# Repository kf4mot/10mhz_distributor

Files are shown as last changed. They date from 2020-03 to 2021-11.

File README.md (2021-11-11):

# 10mhz_distributor
A 10 MHz 3 channel distribution amplifier and low pass filter designed to integrate into a BG7TBL GPSDO. A 5th. order LPF on both the input and outputs allows it to be driven with either sine or square waves and produce a sine output of around 12 dBm into a 50Ω load.
Power consumption is about 130 mA @12V.

[Schematic](https://github.com/kf4mot/10mhz_distributor/blob/master/hardware/10mhz_distributor_r1.pdf)

[Created with KiCAD ver. 5.1.5-3](https://kicad.org)

**Notes worth reading**

1. Schematic and BOM show The Qorvo TQP369182 as the MMIC. TQP369180 was actually used on the first board. The extra gain of the 182 seems unnecessary when driven with a 5V square wave and it may cause oscillation based on past experience. Bias resistors remain at 91Ω. Upgrade at your own risk and let me know how it goes if you try it or any other MMIC.
1. Pads for a optional attn. are on the input. *Trace that shorts R2 should be cut.* **Untested.**
1. Pads for a optional isolation transformer are on the 3rd. output. **Untested.**
1. Jitter and delay/phase shift are untested, but assumed good enough for a inexpensive GPSDO. If you build it and have the lab to test please share your results.
1. I left the input BNC (J3) off of mine and ran a internal wire to the GPSDO output. The BNC could be added by those that want the option to loop the clock or any other suitable input back into the distribution amp. Or those that want to use this as a stand alone general purpose distribution amp.
1. The 50Ω input load (R11) is 0603 size because I happen to have it in my inventory. You could use a 1206 at the R1 position if prefered. Or probably left off altogether if you're driving with a sinewave and bypassing the input filter.
   
Attenuator table for 1% resistors
Attn. |R2 | R1, R3
------------ | ------------- | ---------
3 dB| 17.8Ω | 294Ω
6 dB| 37.4Ω | 150Ω
10 dB | 71.5Ω | 95.3Ω

[Attenuator Calc](https://www.pasternack.com/t-calculator-pi-attn.aspx)

[Licensed under CERN-OHL-S V2. Julian White, 2020](https://www.ohwr.org/project/cernohl/wikis/home)

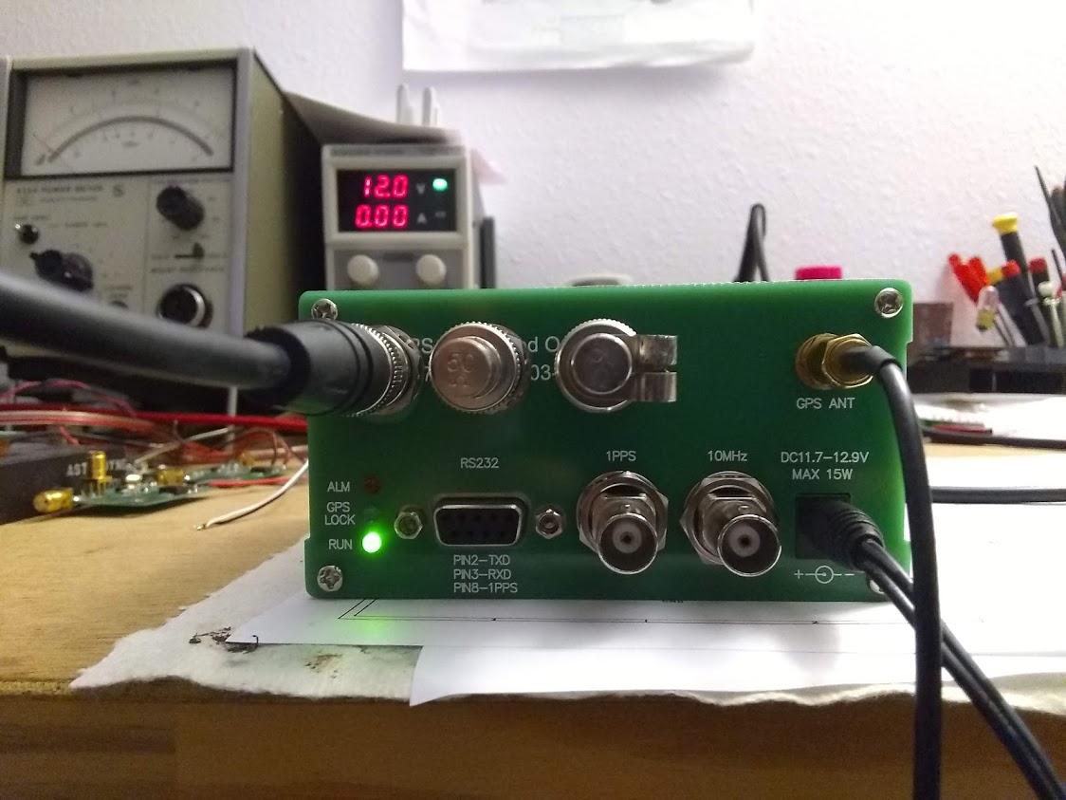
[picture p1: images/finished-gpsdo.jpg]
Complete


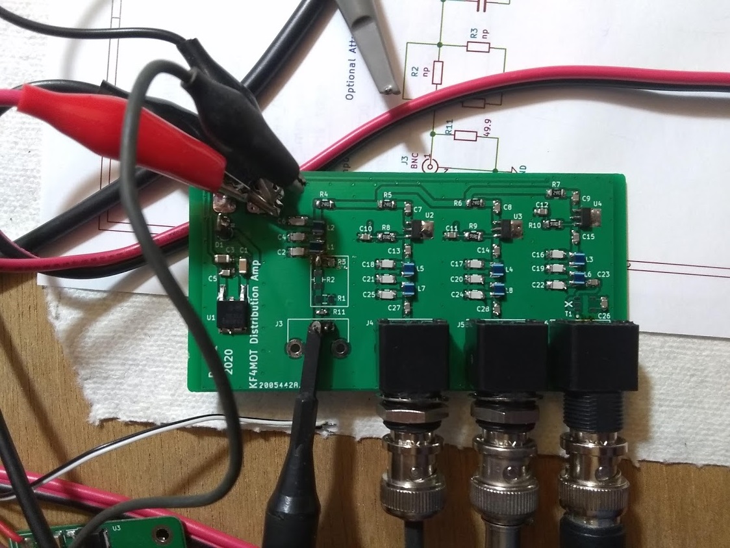
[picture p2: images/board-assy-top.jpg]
BoardTop Board Top


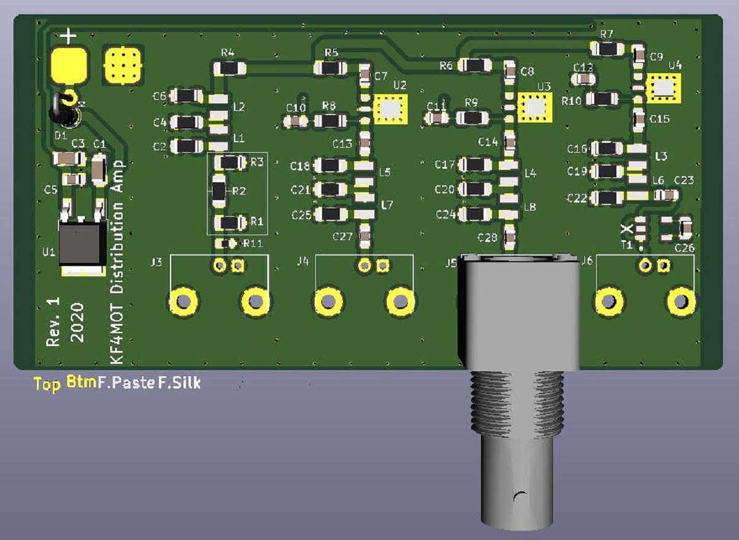
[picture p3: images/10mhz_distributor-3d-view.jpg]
BoardTop 3D Board Top 3D


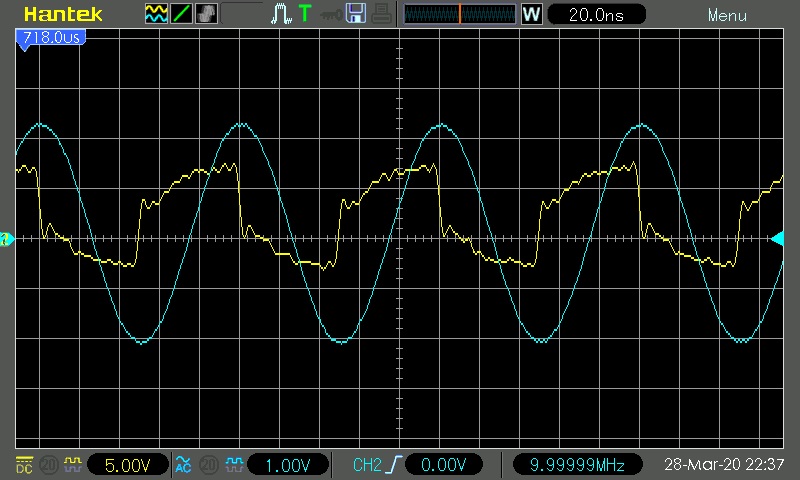
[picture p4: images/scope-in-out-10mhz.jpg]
Input vs. Output


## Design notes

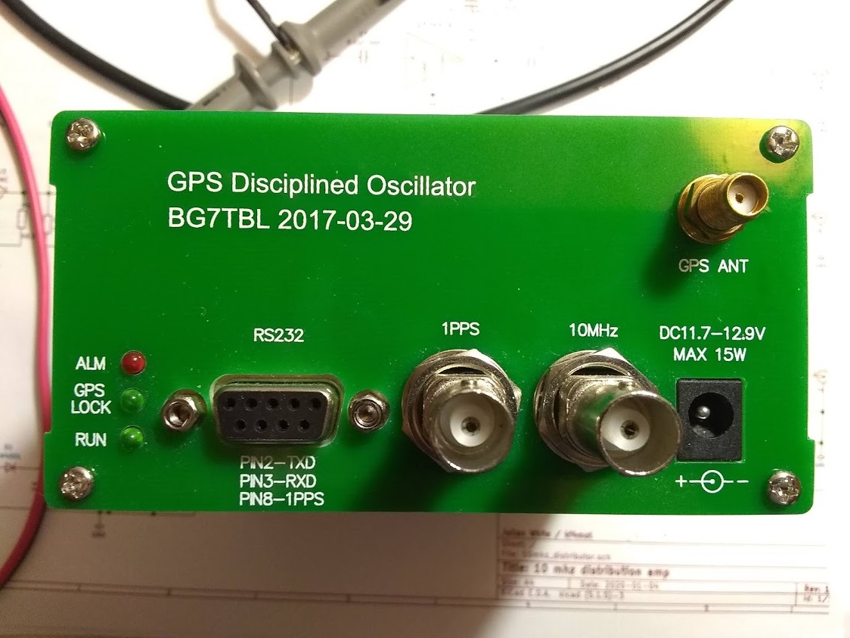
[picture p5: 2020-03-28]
images/before-gpsdo.jpg

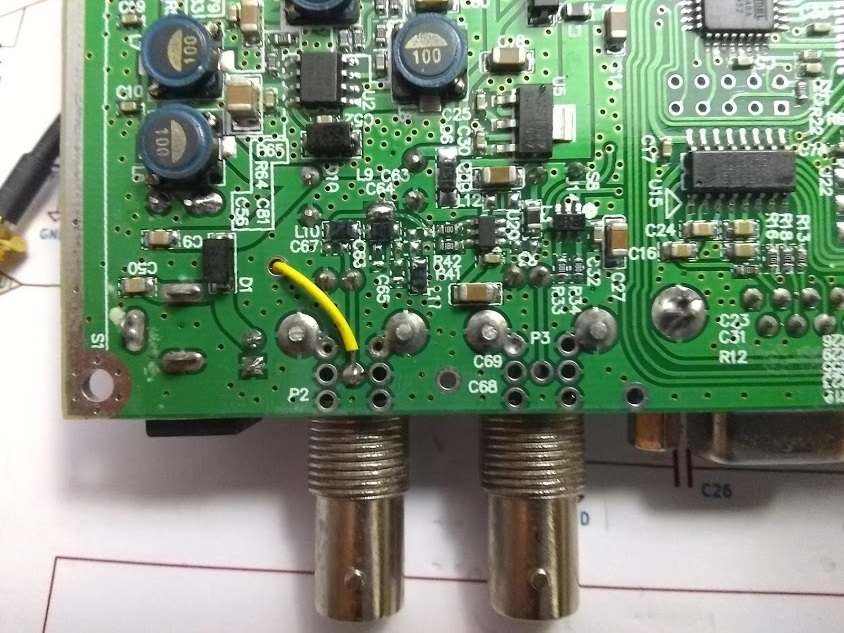
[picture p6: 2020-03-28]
images/bottom.jpg

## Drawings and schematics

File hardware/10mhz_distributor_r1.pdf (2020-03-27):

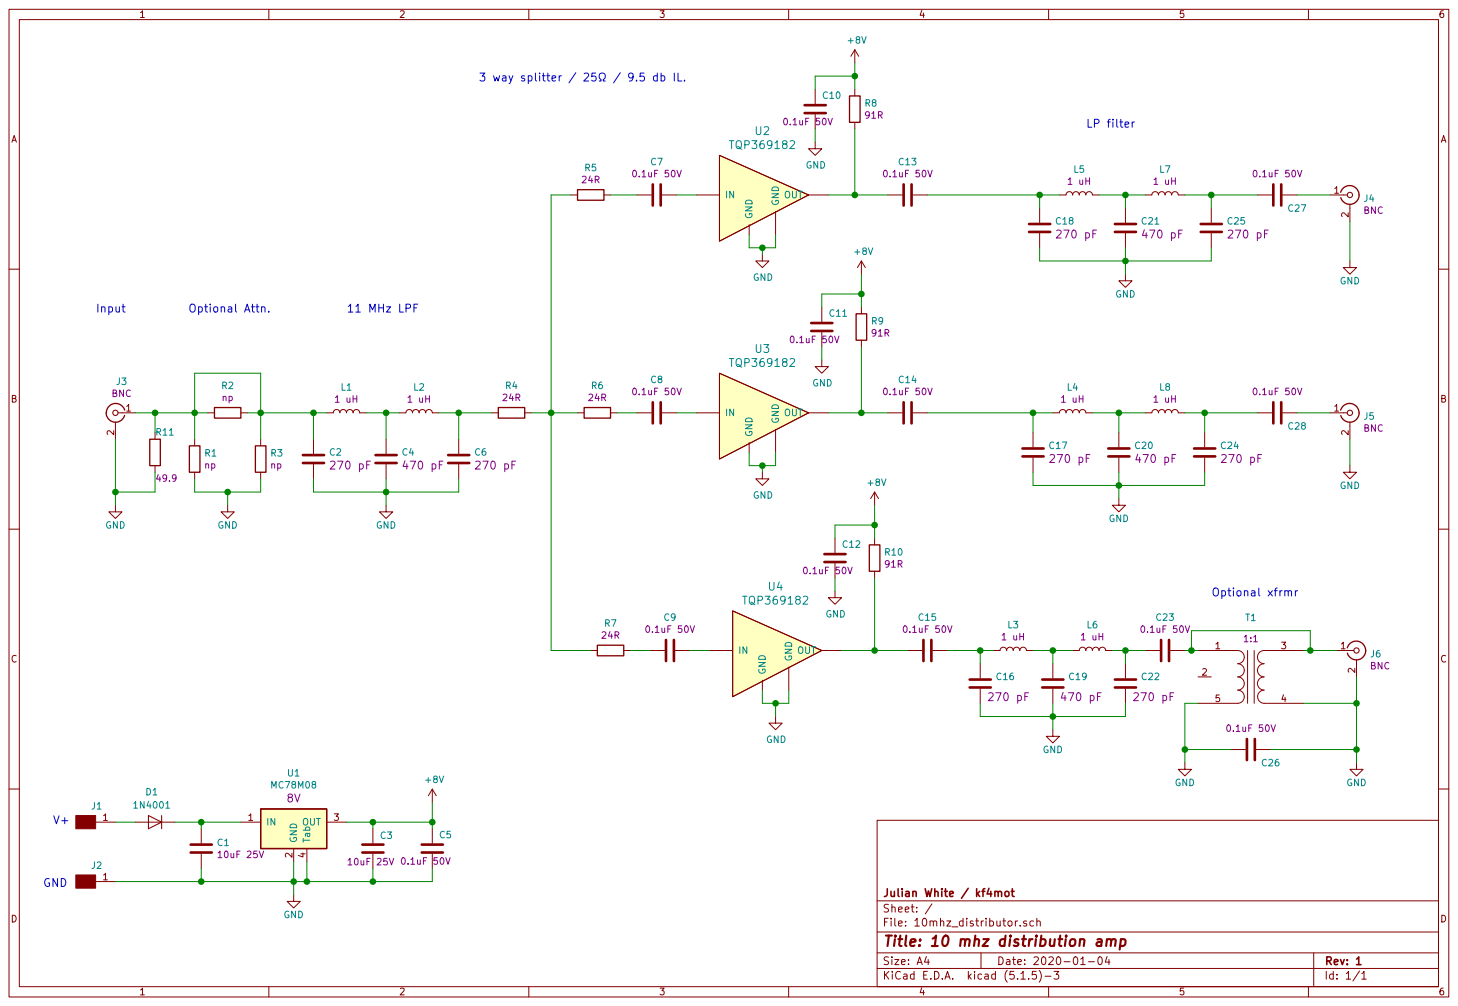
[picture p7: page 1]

3 way splitter / 25 / 9.5 db IL.

File: 10mhz_distributor.sch Sheet: / Julian White / kf4mot

Id: 1/1 Title: 10 mhz distribution amp

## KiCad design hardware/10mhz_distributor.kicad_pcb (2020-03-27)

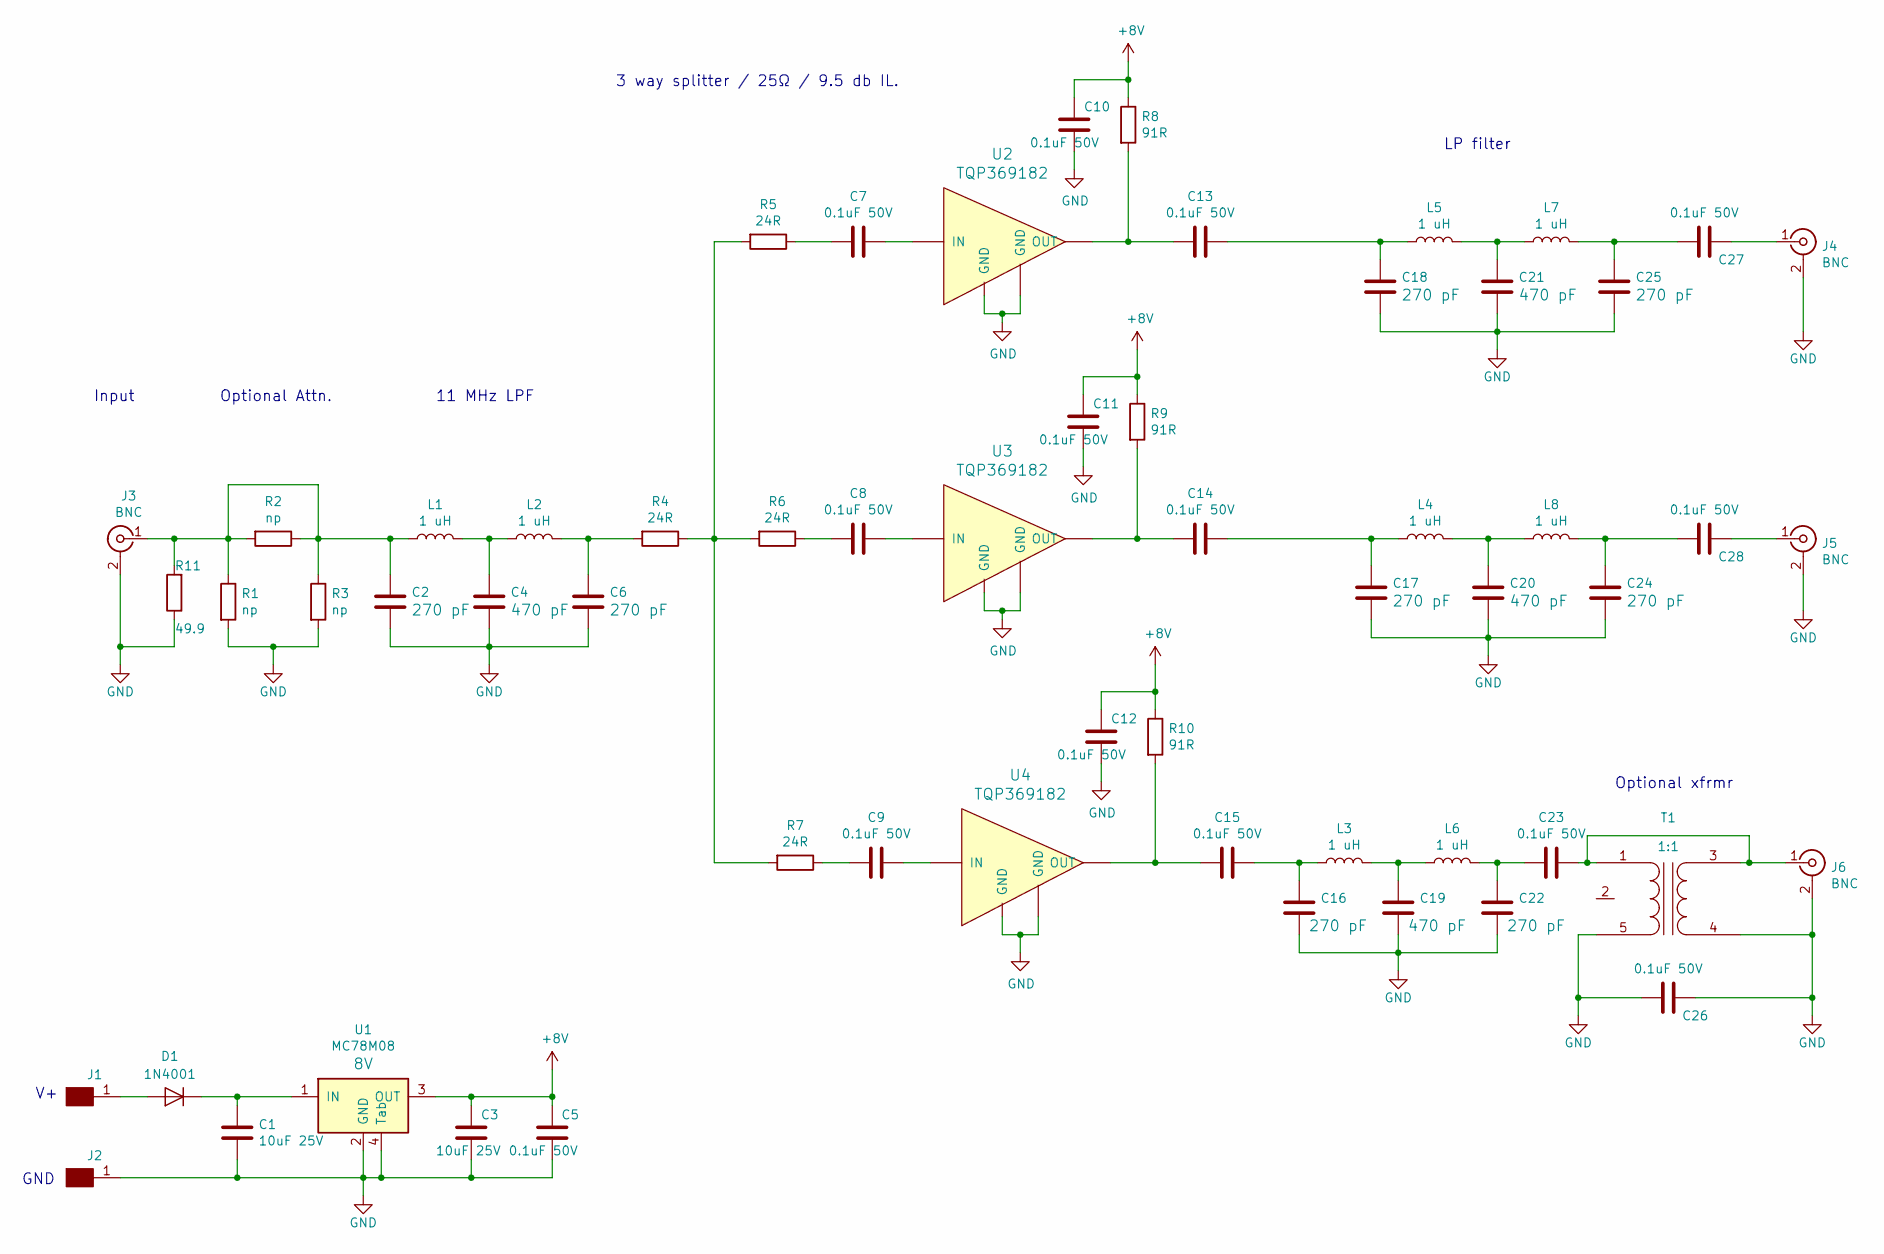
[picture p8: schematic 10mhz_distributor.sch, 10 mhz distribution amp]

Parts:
C1, C3: 10uf_25V_1206; C_1206_3216Metric_Pad1.42x1.75mm_HandSolder; Part Number CGA5L1X7R1E106K160AC
C2, C6, C16, C17, C18, C22, C24, C25: C_270pF_1206_C0G; R_1206_3216Metric_Pad1.42x1.75mm_HandSolder; Part Number 12062A271JAT2A
C4, C19, C20, C21: C_470pF_1206_C0G; R_1206_3216Metric_Pad1.42x1.75mm_HandSolder; Part Number CC1206JRNPOYBN471
C5, C7, C8, C9, C10, C11, C12, C13, C14, C15, C23, C26, C27, C28: 0.1uF_50V_0805_x7r; C_0805_2012Metric_Pad1.15x1.40mm_HandSolder; Part Number C0805C104K5RACTU
D1: 1N4001; D_DO-41_SOD81_P2.54mm_Vertical_AnodeUp; Part Number 1N4004
J1, J2: Conn_5mm_pad; SolderWirePad_single_SMD_5mm
J3, J4, J5, J6: BNC_Molex_0731375003; bnc_molex_0731375003; Part Number 0731375003
L1, L2, L3, L4, L5, L6, L7, L8: L_1uh_2%_1008; L_1008; Part Number LQW2UAS1R0G0CL
R1, R2, R3: R_1206; R_1206_3216Metric_Pad1.42x1.75mm_HandSolder; Part Number np
R4, R5, R6, R7: R_24_sm1206; R_1206_3216Metric_Pad1.42x1.75mm_HandSolder; Part Number CR1206-FX-24R0ELF
R8, R9, R10: R_91_sm1206; R_1206_3216Metric_Pad1.42x1.75mm_HandSolder; Part Number RC1206FR-0791RL
R11: R_49R9_sm0603; R_0603_1608Metric_Pad1.05x0.95mm_HandSolder; Part Number RC0603FR-0749R9L
T1: Transformer_1_1_MABA_007159; MABA-007159_transformer; Part Number MABA-007159-000000
U1: MC78M08; TO-252-2; Part Number MC78M08CDTRKG
U2, U3, U4: TQP369182; SOT-89; Part Number TQP369182

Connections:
+8V: C3.1, C5.2, C10.2, C11.2, C12.2, R8.1, R9.1, R10.1, U1.3 (OUT)
GND: C1.2, C2.2, C3.2, C4.2, C5.1, C6.2, C10.1, C11.1, C12.1, C16.2, C17.2, C18.2, C19.2, C20.2, C21.2, C22.2, C24.2, C25.2, C26.1, C26.2, J2.1, J3.2 (Ext), J4.2 (Ext), J5.2 (Ext), J6.2 (Ext), R1.2, R3.2, R11.1, T1.4 (SA), T1.5 (AB), U1.2 (GND), U1.4 (Tab), U2.2 (GND), U2.4 (GND), U3.2 (GND), U3.4 (GND), U4.2 (GND), U4.4 (GND)
unnamed: C1.1, D1.1 (K), U1.1 (IN)
unnamed: C2.1, J3.1 (In), L1.1, R1.1, R2.1, R2.2, R3.1, R11.2
unnamed: C4.1, L1.2, L2.1
unnamed: C6.1, L2.2, R4.2
unnamed: C7.1, U2.1 (IN)
unnamed: C7.2, R5.1
unnamed: C8.1, U3.1 (IN)
unnamed: C8.2, R6.1
unnamed: C9.1, U4.1 (IN)
unnamed: C9.2, R7.1
unnamed: C13.1, C18.1, L5.1
unnamed: C13.2, R8.2, U2.3 (OUT)
unnamed: C14.1, C17.1, L4.1
unnamed: C14.2, R9.2, U3.3 (OUT)
unnamed: C15.1, C16.1, L3.1
unnamed: C15.2, R10.2, U4.3 (OUT)
unnamed: C19.1, L3.2, L6.1
unnamed: C20.1, L4.2, L8.1
unnamed: C21.1, L5.2, L7.1
unnamed: C22.1, C23.2, L6.2
unnamed: C23.1, J6.1 (In), T1.1 (AA), T1.3 (SB)
unnamed: C24.1, C28.2, L8.2
unnamed: C25.1, C27.2, L7.2
unnamed: C27.1, J4.1 (In)
unnamed: C28.1, J5.1 (In)
unnamed: D1.2 (A), J1.1
unnamed: R4.1, R5.2, R6.2, R7.2

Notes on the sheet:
GND
11 MHz LPF
LP filter
Optional Attn.
Input
3 way splitter / 25Ω / 9.5 db IL.
Optional xfrmr

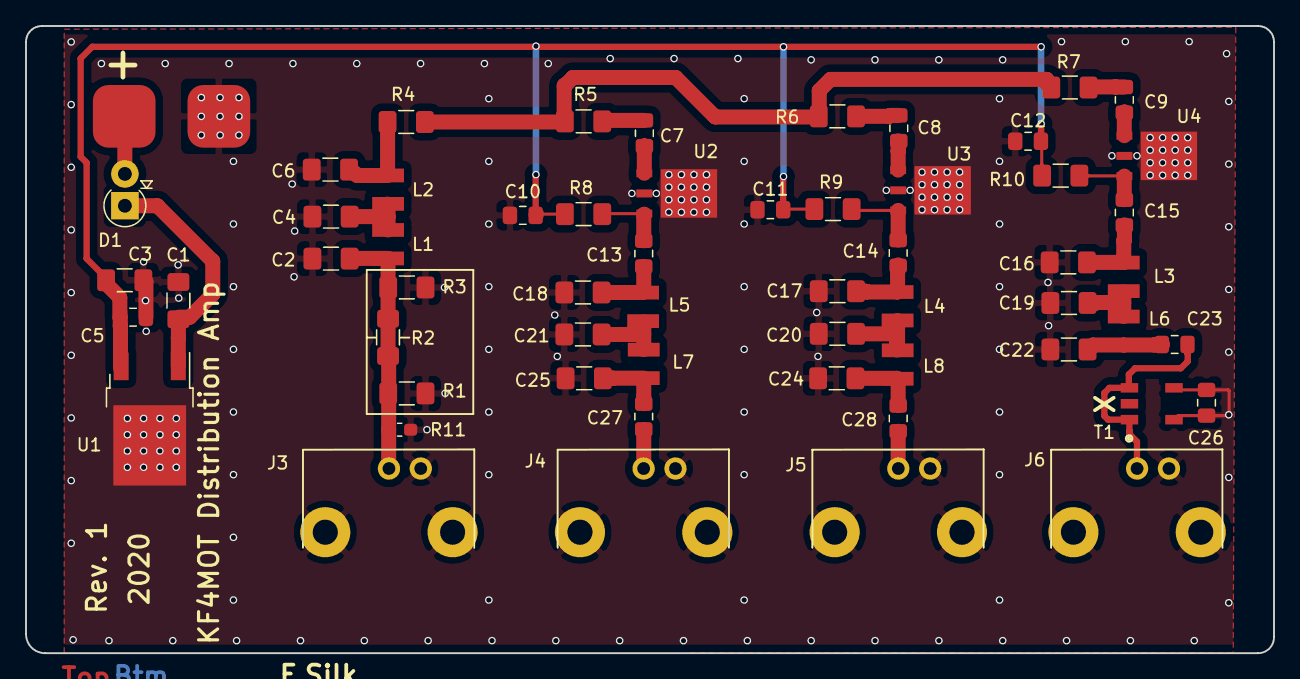
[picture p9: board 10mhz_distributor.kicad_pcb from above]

Board: 2 copper layers, 99.6 x 50.0 mm, 59 parts (0 on the bottom side), 29 nets.

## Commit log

2020-03-28 Create CAD
2021-11-10 Update README.md
    https://forum.kicad.info/t/warning-avoid-all-links-to-kicad-pcb-org-use-kicad-org/31521
